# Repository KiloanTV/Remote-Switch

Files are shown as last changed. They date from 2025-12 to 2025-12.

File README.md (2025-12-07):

<div>
  <h1 align="center">Remote Switch</h1>

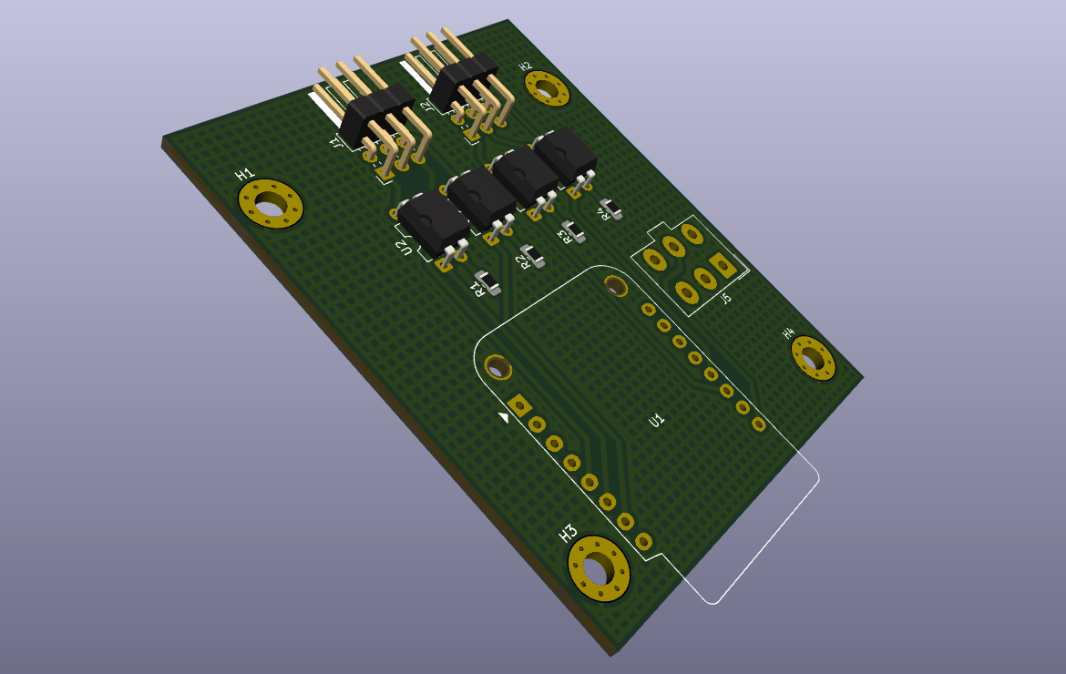
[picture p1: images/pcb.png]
Remote-Switch
  

  <p align="center">
  <a href="https://blueprint.hackclub.com/">
    
  </a>
  </p>
  <h1></h1>
  <p align="center">
    Turn on Devices without touching them. Simple but yet efficient!
  </p>
</div>

<sub align="center">This work is licensed under the
[MIT License](https://mit-license.org).
</sub>

## Table of Contents

- [About](#about)
- [Pictures](#pictures)
- [Bill of Materials](#bill-of-materials)

# About

I need a way to turn the PCs in my rack on and off, ideally centrally and via Wi-Fi. My idea is to use simple optocouplers to simulate the power button and control it with a microcontroller, just like the reset function. The positive LED output will then simply be connected to a GPIO pin of the MCU, allowing it to see whether the PC is on or off. Thats it!

# Pictures

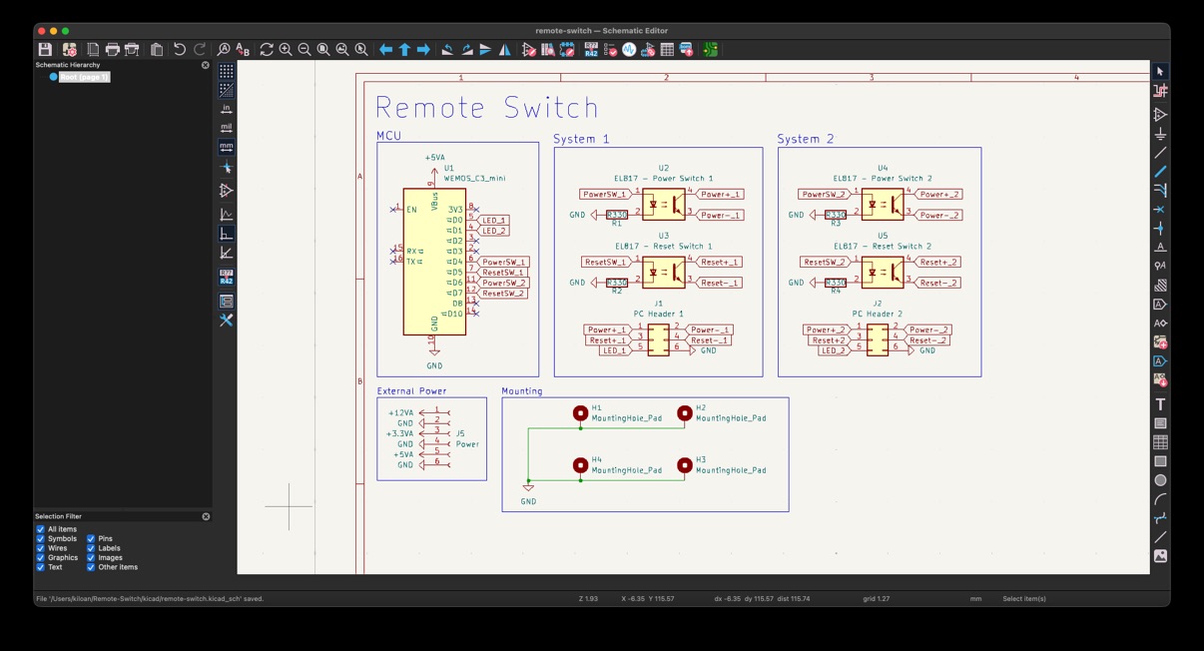
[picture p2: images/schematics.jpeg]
schematics


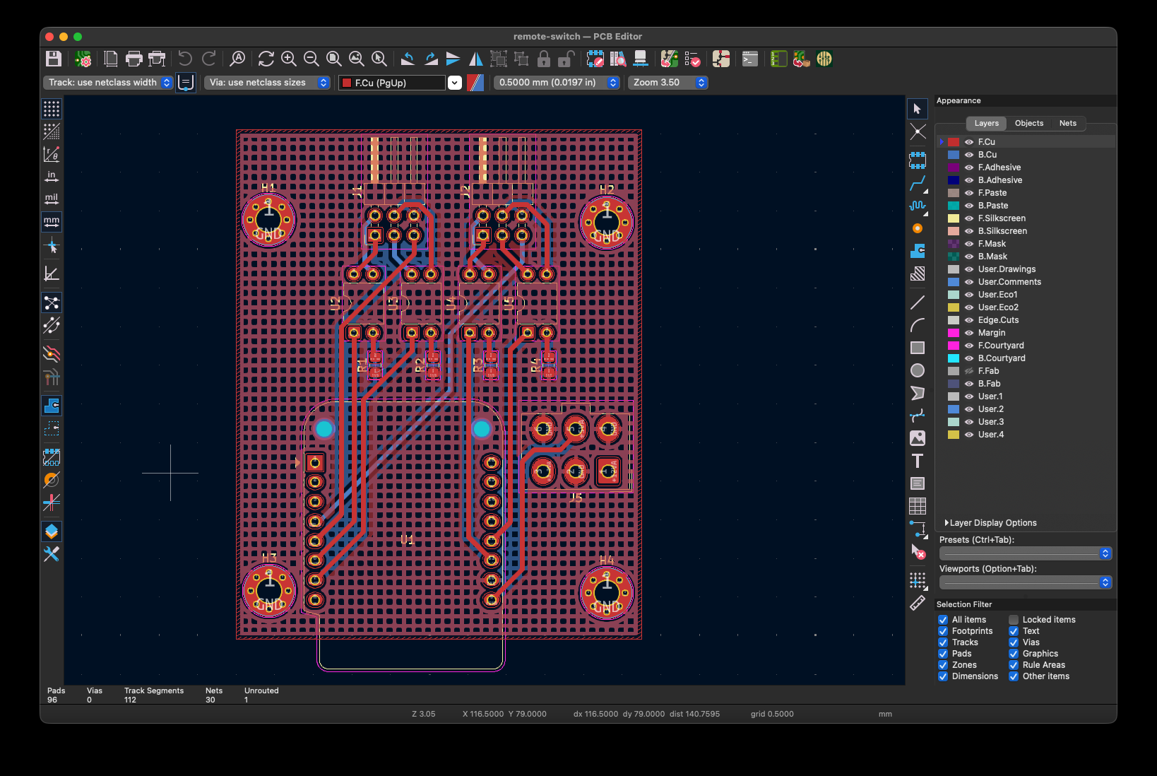
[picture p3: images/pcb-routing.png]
pcb-routing


# Bill of Materials

<details>
<summary><strong>Show Bill Of Materials(BOM) ----></strong></summary>

|Designator |Footprint |Quantity|Value |LCSC Part #|
|---|---|---|---|---|
|J1 |PinHeader_2x03_P2.54mm_Horizontal |1 |PC Header 1 |C41417351  |
|J2 |PinHeader_2x03_P2.54mm_Horizontal |1 |PC Header 2 |C41417351  |
|J5 |Molex_Mini-Fit_Jr_5566-06A_2x03_P4.20mm_Vertical|1 |Power |C471417 |
|R1, R2, R3, R4|0805 |4 |R330 |C17630 |
|U1 |WEMOS_C3_mini |1 |WEMOS_C3_mini | |
|U2 |DIP-4_W7.62mm |1 |EL817 - Power Switch 1|C5353 |
|U3 |DIP-4_W7.62mm |1 |EL817 - Reset Switch 1|C5353 |
|U4 |DIP-4_W7.62mm |1 |EL817 - Power Switch 2|C5353 |
|U5 |DIP-4_W7.62mm |1 |EL817 - Reset Switch 2|C5353 |
|LCSC Quote: 14.32 Dollar | | | | |
|JLCPCB Quote: 6.54 Dollar | | | | |
|Aliexpress Quote: 5.69 Dollar | | | | |
|All together: 26.55 Dollar | | | | |

</details>

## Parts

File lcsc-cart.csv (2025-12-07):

Index | LCSC# | MPN | Manufacturer | Package | Customer # | Description | RoHS | Quantity | MOQ | Multiple | Unit Price($) | Extended Price($) | Product Link
1 | C41417351 | HX PZ2.54-2x3P WC-A | hanxia | Through Hole,Right Angle,P=2.54mm |  | 2x3P 6P Gold Brass -40℃~+105℃ Pin Header Black 2.54mm 2.5mm 6mm 1kV 3mm 3A 2 Right Angle 2.54mm Through Hole,Right Angle,P=2.54mm Headers, Male Pins RoHS | yes | 10 | 10 | 10 | 0.0381 | 0.38 | https://www.lcsc.com/product-detail/C41417351.html
2 | C471417 | 39281063 | MOLEX | Through Hole,P=4.2mm |  | 6P 2x3P Tin -40℃~+105℃ White 4.2mm 600V 3 9A 2 Through Hole 4.2mm Through Hole,P=4.2mm Headers, Male Pins RoHS | yes | 5 | 5 | 5 | 0.3774 | 1.89 | https://www.lcsc.com/product-detail/C471417.html
3 | C17630 | 0805W8F3300T5E | UNI-ROYAL | 0805 |  | 125mW 330Ω 150V ±100ppm/℃ Thick Film Resistor ±1% 0805 Chip Resistor - Surface Mount RoHS | yes | 100 | 100 | 100 | 0.0019 | 0.19 | https://www.lcsc.com/product-detail/C17630.html
4 | C5353 | EL817(B)-F | EVERLIGHT | DIP-4 |  | 50mA 100mV@20mA,1mA 35V 6V DC DIP-4 Transistor, Photovoltaic Output Optoisolators RoHS | yes | 20 | 20 | 20 | 0.0385 | 0.77 | https://www.lcsc.com/product-detail/C5353.html

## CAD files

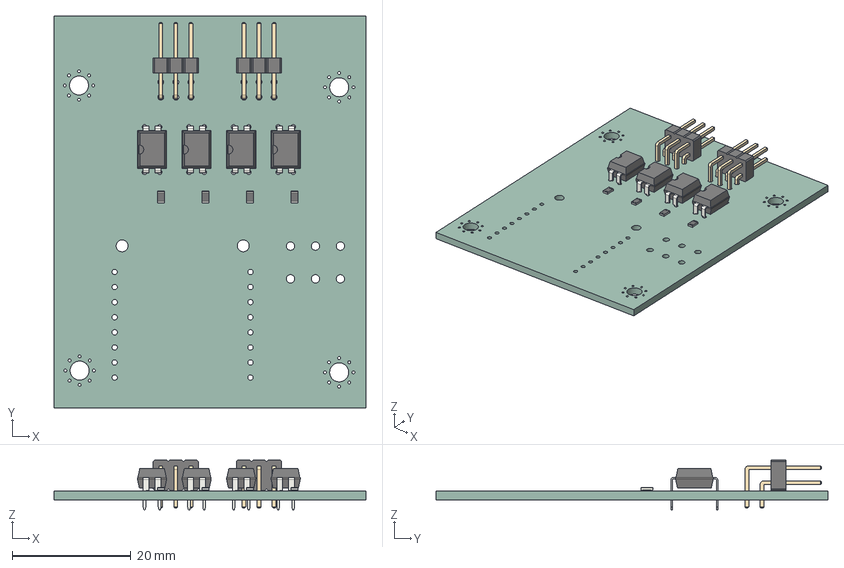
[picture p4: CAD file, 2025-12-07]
pcb/remote-switch.step
52.5 x 66.0 x 8.38 mm
R_0805_2012Metric x 4
PinHeader_2x03_P2.54mm_Horizontal x 2
DIP-4_W7.62mm x 4
remote-switch_PCB

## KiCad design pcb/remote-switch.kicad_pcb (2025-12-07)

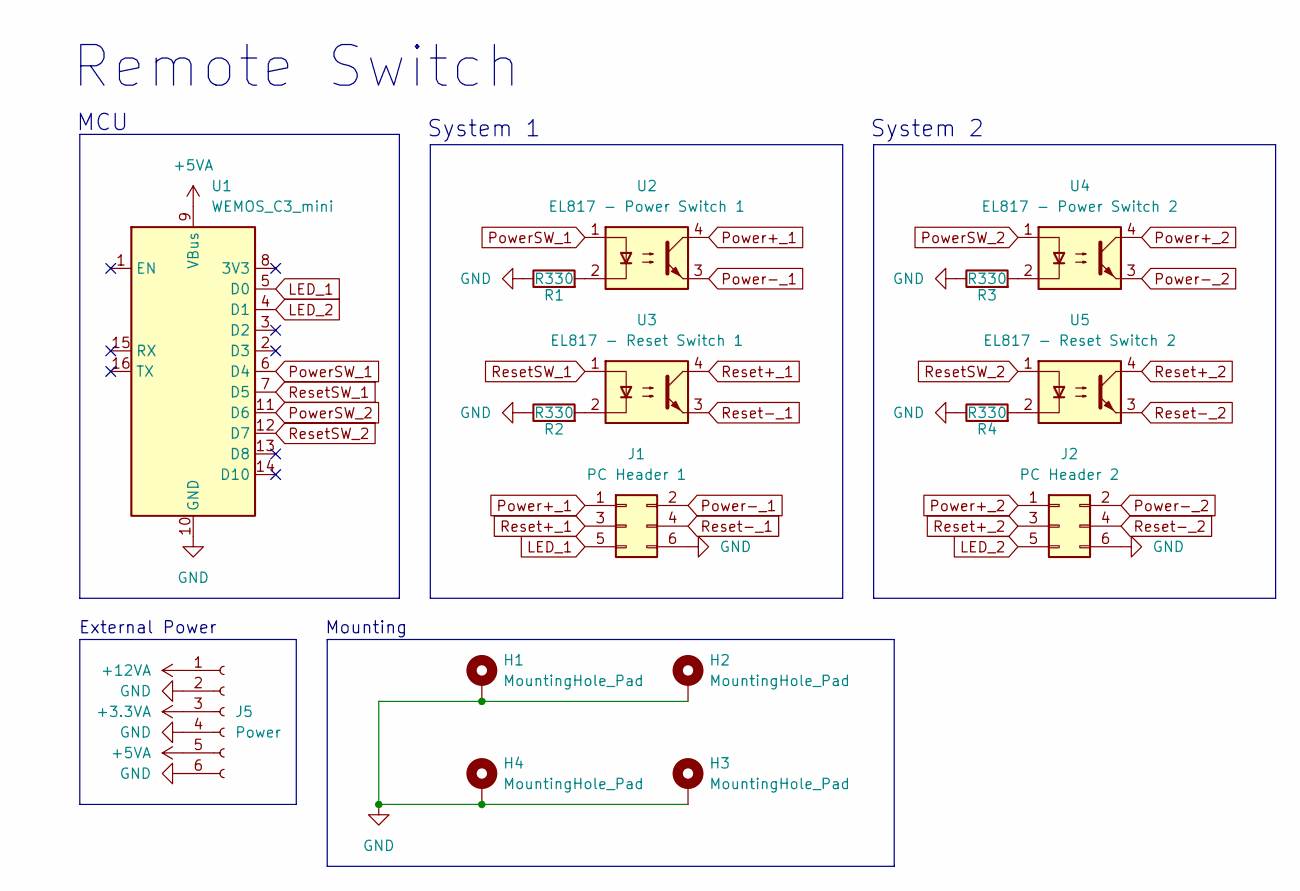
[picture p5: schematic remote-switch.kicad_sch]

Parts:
H1, H2, H3, H4: MountingHole_Pad; MountingHole_3.2mm_M3_Pad_Via
J1: PC Header 1; PinHeader_2x03_P2.54mm_Horizontal; LCSC C41417351
J2: PC Header 2; PinHeader_2x03_P2.54mm_Horizontal; LCSC C41417351
J5: Power; Molex_Mini-Fit_Jr_5566-06A_2x03_P4.20mm_Vertical; LCSC C471417
R1, R2, R3, R4: R330; R_0805_2012Metric_Pad1.20x1.40mm_HandSolder; LCSC C17630
U1: WEMOS_C3_mini
U2: EL817 - Power Switch 1; DIP-4_W7.62mm; LCSC C5353
U3: EL817 - Reset Switch 1; DIP-4_W7.62mm; LCSC C5353
U4: EL817 - Power Switch 2; DIP-4_W7.62mm; LCSC C5353
U5: EL817 - Reset Switch 2; DIP-4_W7.62mm; LCSC C5353

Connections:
+3.3VA: J5.3
+5VA: J5.5, U1.9 (VBus)
+12VA: J5.1
GND: H1.1, H2.1, H3.1, H4.1, J1.6, J2.6, J5.2, J5.4, J5.6, R1.1, R2.1, R3.1, R4.1, U1.10 (GND)
LED_1: J1.5, U1.5 (D0)
LED_2: J2.5, U1.4 (D1)
unnamed: R1.2, U2.2
unnamed: R2.2, U3.2
unnamed: R3.2, U4.2
unnamed: R4.2, U5.2
Power+_1: J1.1, U2.4
Power+_2: J2.1, U4.4
Power-_1: J1.2, U2.3
Power-_2: J2.2, U4.3
PowerSW_1: U1.6 (D4), U2.1
PowerSW_2: U1.11 (D6), U4.1
Reset+_1: J1.3, U3.4
Reset+_2: J2.3, U5.4
Reset-_1: J1.4, U3.3
Reset-_2: J2.4, U5.3
ResetSW_1: U1.7 (D5), U3.1
ResetSW_2: U1.12 (D7), U5.1

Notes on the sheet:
System 2
System 1
MCU
Mounting
External Power
Remote Switch

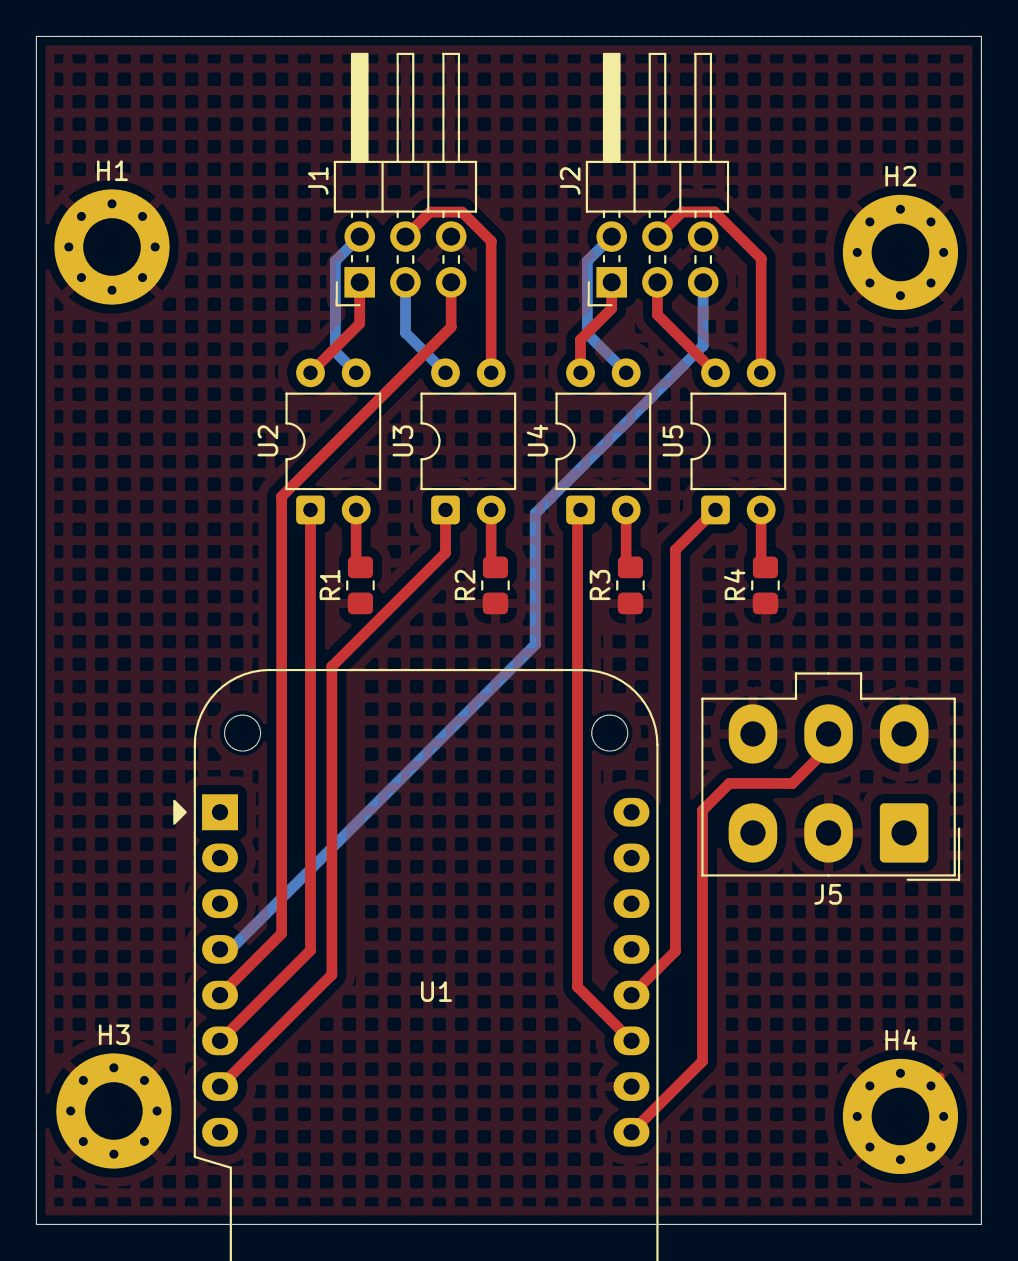
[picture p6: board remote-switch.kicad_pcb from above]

Board: 2 copper layers, 52.5 x 66.0 mm, 16 parts (0 on the bottom side), 20 nets.

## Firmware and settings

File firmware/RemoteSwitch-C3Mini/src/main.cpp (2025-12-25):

#include <Arduino.h>
#include <WiFi.h>
#include <WebServer.h>

const char* ssid = "SSID";
const char* password = "PASSWORD";

// for C3 Mini
#define PC1_LED 5
#define PC2_LED 4
#define PC1_POWER 6
#define PC1_RESET 7
#define PC2_POWER 11
#define PC2_RESET 12

WebServer server(80);

void pressButton(int pin, int duration = 200) {
  digitalWrite(pin, HIGH);
  delay(duration);
  digitalWrite(pin, LOW);
}

void handleRoot() {
  bool pc1On = digitalRead(PC1_LED);
  bool pc2On = digitalRead(PC2_LED);
  
  String html = "<html><head><title>PC Remote Switch</title>";
  html += "<meta name='viewport' content='width=device-width, initial-scale=1'>";
  html += "<style>body{font-family:Arial;margin:20px;}";
  html += ".pc{border:2px solid #333;padding:15px;margin:10px 0;border-radius:8px;}";
  html += ".on{background:#d4edda;}.off{background:#f8d7da;}";
  html += "button{padding:10px 20px;margin:5px;font-size:16px;cursor:pointer;}</style></head><body>";
  
  html += "<h1>PC Remote Switch</h1>";
  
  html += "<div class='pc " + String(pc1On ? "on" : "off") + "'>";
  html += "<h2>PC 1 - " + String(pc1On ? "ON" : "OFF") + "</h2>";
  html += "<button onclick=\"location.href='/pc1/power'\">Power</button>";
  html += "<button onclick=\"location.href='/pc1/reset'\">Reset</button></div>";
  
  html += "<div class='pc " + String(pc2On ? "on" : "off") + "'>";
  html += "<h2>PC 2 - " + String(pc2On ? "ON" : "OFF") + "</h2>";
  html += "<button onclick=\"location.href='/pc2/power'\">Power</button>";
  html += "<button onclick=\"location.href='/pc2/reset'\">Reset</button></div>";
  
  html += "</body></html>";
  server.send(200, "text/html", html);
}

void setup() {
  Serial.begin(115200);
  
  // Configure pins
  pinMode(PC1_LED, INPUT);
  pinMode(PC2_LED, INPUT);
  pinMode(PC1_POWER, OUTPUT);
  pinMode(PC1_RESET, OUTPUT);
  pinMode(PC2_POWER, OUTPUT);
  pinMode(PC2_RESET, OUTPUT);
  
  digitalWrite(PC1_POWER, LOW);
  digitalWrite(PC1_RESET, LOW);
  digitalWrite(PC2_POWER, LOW);
  digitalWrite(PC2_RESET, LOW);
  
  // Connect to WiFi
  Serial.print("Connecting to WiFi");
  WiFi.begin(ssid, password);
  while (WiFi.status() != WL_CONNECTED) {
    delay(500);
    Serial.print(".");
  }
  Serial.println("\nConnected! IP: " + WiFi.localIP().toString());
  
  // Setup web routes
  server.on("/", handleRoot);
  server.on("/pc1/power", []() {
    pressButton(PC1_POWER);
    server.sendHeader("Location", "/");
    server.send(303);
  });
  server.on("/pc1/reset", []() {
    pressButton(PC1_RESET);
    server.sendHeader("Location", "/");
    server.send(303);
  });
  server.on("/pc2/power", []() {
    pressButton(PC2_POWER);
    server.sendHeader("Location", "/");
    server.send(303);
  });
  server.on("/pc2/reset", []() {
    pressButton(PC2_RESET);
    server.sendHeader("Location", "/");
    server.send(303);
  });
  
  server.begin();
  Serial.println("Web server started");
}

void loop() {
  server.handleClient();
}

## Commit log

2025-12-07 add files
    _ Kian
    [remote-switch.kicad_pcb, remote-switch.kicad_sch, remote-switch.step]
2025-12-07 revision
    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
    [remote-switch.kicad_pcb, remote-switch.kicad_sch, remote-switch.step]
2025-12-07 add .csv files
    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
    [bom.csv, designators.csv, lcsc-cart.csv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]
